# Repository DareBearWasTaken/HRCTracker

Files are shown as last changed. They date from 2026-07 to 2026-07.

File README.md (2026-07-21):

# Handheld Cadence Tracker

A responsive handheld walking and running cadence tracker built with an
ESP32-C5, an MPU9250-series inertial sensor, and a 128×64 SSD1306 OLED.

The tracker measures rhythmic handheld motion, filters out gravity and
orientation changes, validates step timing, and displays both the current and
average cadence in steps per minute (SPM). An LED provides immediate feedback
whenever a step is detected.

## Features

- 125 Hz accelerometer and gyroscope sampling
- Orientation-independent handheld motion detection
- Automatic stillness calibration at startup
- Adaptive accelerometer and gyroscope thresholds
- Hysteretic peak detection and false-motion rejection
- Rhythm locking for more reliable step validation
- Recovery from an occasional missed step impact
- Session step counter
- Average active cadence display
- Responsive current cadence display
- Immediate, non-blocking LED step indication
- OLED and sensor access coordinated to protect sample timing
- No button required

## Display

During tracking, the OLED shows:

- **AVG SPM:** Average cadence across accepted active step intervals
- **NOW:** Smoothed current cadence
- **STEPS:** Total confirmed and recovered steps
- **MOT:** Live motion-strength indicator
- **AVG CAD / AVG SEEK:** Whether a stable walking or running rhythm has been
  established

Pauses and rejected hand movements are not included in the average cadence.
The average remains available if rhythm lock is temporarily lost.

## Hardware

- ESP32-C5 development board
- MPU9250, MPU9255, or MPU6500 motion sensor
- 128×64 SSD1306 I²C OLED at address `0x3C` or `0x3D`
- Indicator LED
- 220–330 Ω LED resistor
- Jumper wires or a custom PCB

## Wiring

The firmware defaults to the original split-bus wiring below.

| Device | Signal | ESP32-C5 pin |
|---|---|---:|
| OLED | SDA | GPIO23 |
| OLED | SCL | GPIO24 |
| MPU | SDA | GPIO25 |
| MPU | SCL | GPIO26 |
| LED | Anode through 220–330 Ω resistor | GPIO2 |
| LED | Cathode | GND |

Connect the ESP32-C5, OLED, and MPU grounds together. Power each module using
the voltage supported by the specific breakout board being used.

The ESP32-C5 has one high-performance I²C controller that can be routed to the
arbitrary GPIO pins above. The firmware therefore locks the controller during
an OLED transfer, selects the OLED pins, transmits one frame, restores the MPU
pins, and releases the sensor task. The display refresh is limited to 2 FPS so
these interruptions remain short and infrequent.

## Firmware requirements

- Arduino IDE 2.x
- Espressif ESP32 Arduino core with ESP32-C5 support
- [Adafruit GFX Library](https://github.com/adafruit/Adafruit-GFX-Library)
- [Adafruit SSD1306](https://github.com/adafruit/Adafruit_SSD1306)

The MPU is configured directly through its registers. A separate MPU9250
Arduino library is not required.

## Installation

1. Install the Espressif ESP32 board package in Arduino IDE.
2. Install **Adafruit GFX Library** and **Adafruit SSD1306** using Library
   Manager.
3. Open [`cadence_tracker_screen_average.ino`](cadence_tracker_screen_average.ino).
4. Select **ESP32C5 Dev Module** as the board.
5. Select the correct serial port.
6. Compile and upload the sketch.

The firmware has been compile-tested with the following board identifier:

```text
esp32:esp32:esp32c5
```

## Using the tracker

1. Turn on or reset the tracker.
2. Confirm that the LED flashes three times during its startup test.
3. Hold the tracker completely still while the calibration screen reaches
   100%.
4. Hold the tracker naturally and begin walking or running.
5. The first valid motion flashes the LED immediately.
6. Two plausibly timed detections establish rhythm lock and begin the cadence
   display.

If the device moves repeatedly during calibration, the stable calibration
window restarts automatically.

## How cadence is calculated

The accelerometer magnitude is used so detection does not depend on the
orientation of the device. A slow baseline removes gravity and gradual hand
orientation changes. Filtered gyroscope motion then corroborates the
acceleration signal.

Candidate peaks must satisfy motion-strength, timing, and refractory-period
checks. After rhythm lock:

- Recent accepted intervals produce the responsive **NOW** cadence.
- All accepted active intervals produce the session **AVG SPM** cadence.
- A gap near two expected periods can recover one weak or missed impact.
- Pauses and rejected peaks do not lower the active-cadence average.

## Configuration and tuning

The default values are intended as a balanced starting point for handheld
walking and running. Test the tracker before changing them.

Useful constants near the top of the sketch include:

| Constant | Purpose |
|---|---|
| `SENSOR_PERIOD_MS` | Sensor sampling interval |
| `DISPLAY_PERIOD_MS` | OLED refresh interval |
| `MIN_STEP_INTERVAL_MS` | Maximum allowed cadence |
| `MAX_STEP_INTERVAL_MS` | Minimum cadence used while seeking rhythm |
| `PEAK_TRIGGER_SCORE` | Motion strength required to open a candidate peak |
| `PEAK_RELEASE_SCORE` | Hysteresis level used to finish a peak |

For missed real steps, reduce the lower acceleration-threshold clamp slightly.
For false steps caused by ordinary hand movement, increase
`PEAK_TRIGGER_SCORE` in small increments. Change only one value at a time and
test at multiple walking and running speeds.

## KiCad hardware files

KiCad design files for the custom cadence-tracker hardware will be added to
this repository. The planned hardware release includes:

- KiCad project file (`.kicad_pro`)
- Schematic (`.kicad_sch`)
- PCB layout (`.kicad_pcb`)
- Component and connector details
- Fabrication outputs and a bill of materials when available

A recommended repository location is:

```text
hardware/
└── kicad/
    ├── handheld_cadence_tracker.kicad_pro
    ├── handheld_cadence_tracker.kicad_sch
    └── handheld_cadence_tracker.kicad_pcb
```

Until those files are uploaded, the wiring table above is the reference for
building the prototype.

## Suggested repository structure

```text
.
├── cadence_tracker_screen_average.ino
├── README.md
├── hardware/
│   └── kicad/                 # KiCad files will be added here
└── docs/                      # Optional photos and build notes
```

## Troubleshooting

### OLED remains blank

- Confirm SDA is connected to GPIO23 and SCL to GPIO24.
- Confirm the OLED is an I²C SSD1306 display.
- Check whether its address is `0x3C` or `0x3D`; the firmware tries both.
- Verify common ground and the module's supply voltage.
- Open Serial Monitor at 115200 baud and check for `OLED not found`.

### Tracker stays on the calibration screen

Place it on a stable surface or hold it completely still. Sustained movement
intentionally restarts calibration.

### Cadence remains blank

The tracker needs two plausibly timed motion peaks before rhythm lock. Confirm
that the LED responds while walking naturally.

### MPU initialization fails

- Confirm SDA is connected to GPIO25 and SCL to GPIO26.
- Check power and ground.
- The firmware checks MPU addresses `0x68` and `0x69` automatically.

No license has been selected yet. Add a `LICENSE` file before distributing or
accepting contributions if you want to define reuse terms explicitly.

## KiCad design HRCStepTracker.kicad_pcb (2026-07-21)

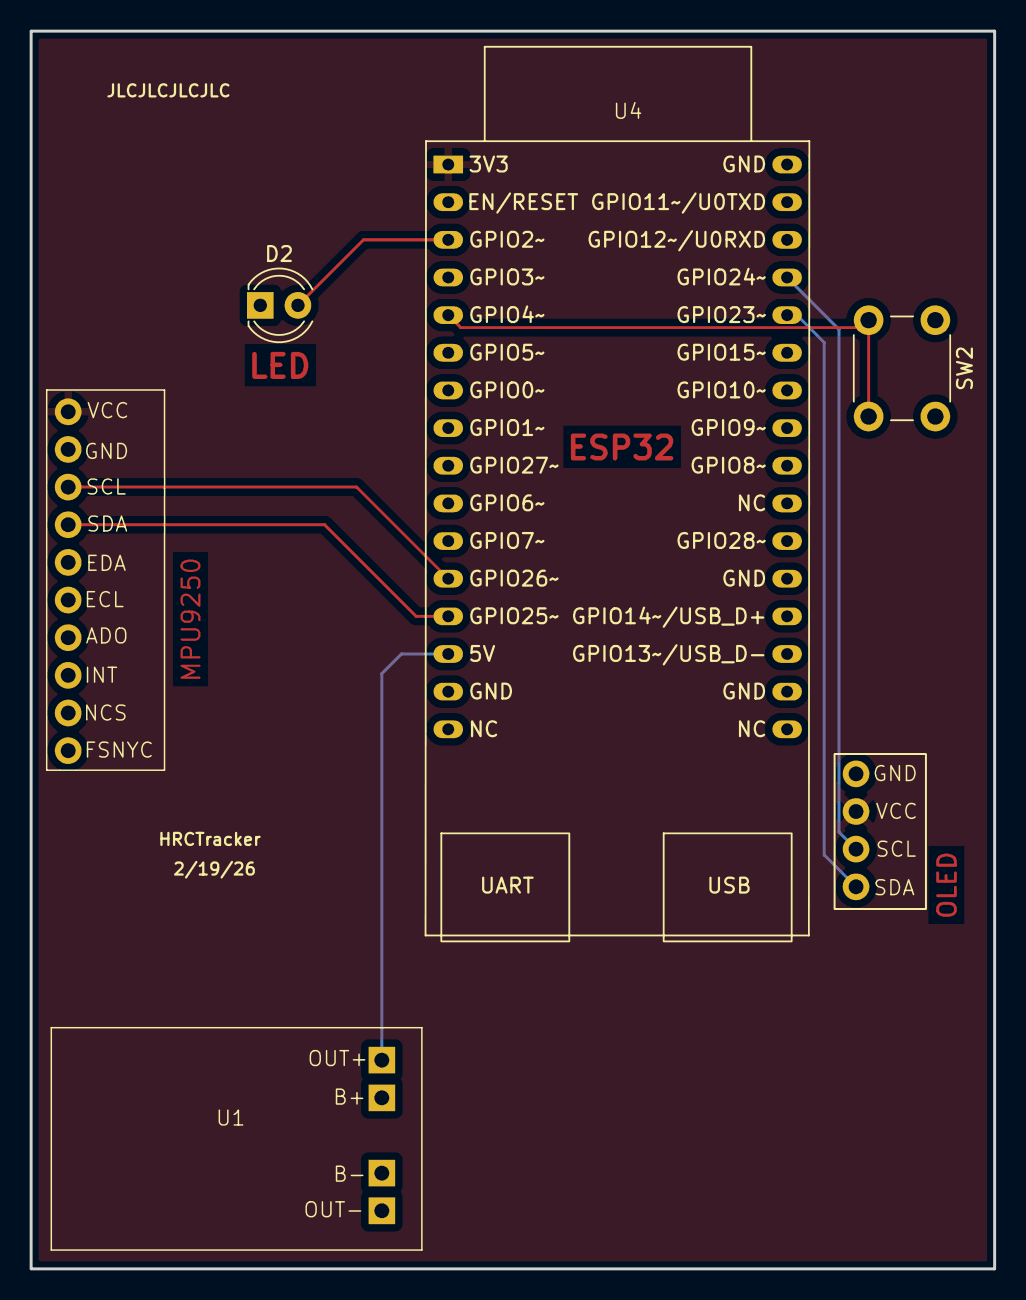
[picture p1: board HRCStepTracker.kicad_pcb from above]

Board: 4 copper layers, 65.0 x 83.5 mm, 6 parts (0 on the bottom side), 9 nets.

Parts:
D2: LED; LED_D4.0mm
SW2: SW_Push; SW_PUSH_6mm_H4.3mm
U1: TP4056
U4: ESP32-C5-DevKitC-1
U5: SSD1306
U6: MPU6500

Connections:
+3V3: U4.1 (3V3), U5.2 (VCC), U6.1 (VCC)
+5V: U1.1 (OUT+), U4.14 (5V)
GND: D2.1 (K), SW2.1, U1.4 (OUT-), U4.15 (GND), U4.18 (GND), U4.21 (GND), U4.32 (GND), U5.1 (GND), U6.2 (GND)
unnamed: D2.2 (A), U4.3 (GPIO2/MTMS)
unnamed: SW2.2, U4.5 (GPIO4/MTCK)
unnamed: U4.28 (GPIO23), U5.4 (SDA)
unnamed: U4.29 (GPIO24), U5.3 (SCL)
unnamed: U4.13 (GPIO25), U6.4 (SDA)
unnamed: U4.12 (GPIO26), U6.3 (SCL)

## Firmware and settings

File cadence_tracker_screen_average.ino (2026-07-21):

#include <Wire.h>
#include <Adafruit_GFX.h>
#include <Adafruit_SSD1306.h>
#include <math.h>
#include <string.h>

// ============================================================
// HANDHELD CADENCE TRACKER -- low-latency ESP32-C5 edition
// ============================================================
//
// Default wiring (matches the original tracker):
//   OLED SDA -> GPIO23      OLED SCL -> GPIO24
//   MPU SDA  -> GPIO25      MPU SCL  -> GPIO26
//   LED +    -> GPIO2 through a 220-330 ohm resistor
//   LED -    -> GND
//
// ESP32-C5 has only one high-performance I2C controller that can use
// these arbitrary pins. This version safely locks that controller,
// changes pins for the OLED frame, restores the MPU pins, and then
// releases the sensor task. The OLED updates at 2 Hz, keeping the
// unavoidable sampling interruption short and infrequent.
// ============================================================

#ifndef USE_ORIGINAL_WIRING
#define USE_ORIGINAL_WIRING 1
#endif

#ifndef ENABLE_STEP_DEBUG
#define ENABLE_STEP_DEBUG 0
#endif

// ------------------------------------------------------------
// Hardware
// ------------------------------------------------------------

constexpr int MPU_SDA_PIN = 25;
constexpr int MPU_SCL_PIN = 26;

#if USE_ORIGINAL_WIRING
constexpr int OLED_SDA_PIN = 23;
constexpr int OLED_SCL_PIN = 24;
constexpr int LED_PIN = 2;
#define OLED_WIRE Wire
#else
// Optional maximum-performance wiring using the C5's fixed LP-I2C pins.
constexpr int OLED_SDA_PIN = 2;
constexpr int OLED_SCL_PIN = 3;
constexpr int LED_PIN = 4;
#define OLED_WIRE Wire1
#endif

constexpr bool LED_ACTIVE_HIGH = true;
constexpr uint32_t I2C_CLOCK_HZ = 400000;
constexpr uint16_t I2C_TIMEOUT_MS = 8;

// ------------------------------------------------------------
// OLED
// ------------------------------------------------------------

constexpr int SCREEN_WIDTH = 128;
constexpr int SCREEN_HEIGHT = 64;
constexpr int OLED_RESET_PIN = -1;

// Keeping clkDuring and clkAfter at 400 kHz avoids an extra clock change
// during each safely time-sliced OLED update.
Adafruit_SSD1306 display(
  SCREEN_WIDTH,
  SCREEN_HEIGHT,
  &OLED_WIRE,
  OLED_RESET_PIN,
  I2C_CLOCK_HZ,
  I2C_CLOCK_HZ
);

bool displayAvailable = false;
uint8_t oledAddress = 0;

// ------------------------------------------------------------
// MPU9250 registers and scale factors
// ------------------------------------------------------------

constexpr uint8_t MPU_ADDRESS_LOW = 0x68;
constexpr uint8_t MPU_ADDRESS_HIGH = 0x69;

constexpr uint8_t REG_SMPLRT_DIV = 0x19;
constexpr uint8_t REG_CONFIG = 0x1A;
constexpr uint8_t REG_GYRO_CONFIG = 0x1B;
constexpr uint8_t REG_ACCEL_CONFIG = 0x1C;
constexpr uint8_t REG_ACCEL_CONFIG_2 = 0x1D;
constexpr uint8_t REG_INT_PIN_CFG = 0x37;
constexpr uint8_t REG_INT_ENABLE = 0x38;
constexpr uint8_t REG_INT_STATUS = 0x3A;
constexpr uint8_t REG_PWR_MGMT_1 = 0x6B;
constexpr uint8_t REG_PWR_MGMT_2 = 0x6C;
constexpr uint8_t REG_WHO_AM_I = 0x75;

constexpr float ACCEL_COUNTS_PER_G = 8192.0f;   // +/-4 g
constexpr float GYRO_COUNTS_PER_DPS = 65.5f;    // +/-500 dps

uint8_t mpuAddress = 0;

// ------------------------------------------------------------
// Application and UI state
// ------------------------------------------------------------

enum AppState : uint8_t {
  STATE_CALIBRATING,
  STATE_TRACKING,
  STATE_ERROR
};

struct UiSnapshot {
  AppState state;
  float calibrationProgress;
  bool calibrationMoving;
  bool rhythmLocked;
  float averageCadence;
  float currentCadence;
  float motionScore;
  uint32_t stepCount;
  uint32_t sensorFailures;
  uint32_t missedDeadlines;
  uint32_t sessionStartedAt;
  char errorMessage[24];
};

UiSnapshot uiSnapshot = {
  STATE_CALIBRATING,
  0.0f,
  false,
  false,
  0.0f,
  0.0f,
  0.0f,
  0,
  0,
  0,
  0,
  "NONE"
};

portMUX_TYPE uiMux = portMUX_INITIALIZER_UNLOCKED;

AppState appState = STATE_CALIBRATING;
char errorMessage[24] = "NONE";

// ------------------------------------------------------------
// Timing
// ------------------------------------------------------------

constexpr uint32_t SENSOR_PERIOD_MS = 8;      // MPU configured for 125 Hz
constexpr uint32_t DISPLAY_PERIOD_MS = 500;   // 2 FPS; protects sensor timing
constexpr uint32_t CALIBRATION_SAMPLE_COUNT = 375; // 3 stable seconds

uint32_t lastDisplayAt = 0;
uint32_t sessionStartedAt = 0;

#if USE_ORIGINAL_WIRING
enum PrimaryBusTarget : uint8_t {
  PRIMARY_BUS_NONE,
  PRIMARY_BUS_MPU,
  PRIMARY_BUS_OLED
};

PrimaryBusTarget primaryBusTarget = PRIMARY_BUS_NONE;
SemaphoreHandle_t i2cAccessMutex = nullptr;
#endif

// ------------------------------------------------------------
// LED -- immediate, non-blocking pulse
// ------------------------------------------------------------

constexpr uint32_t LED_PULSE_MS = 45;
volatile bool ledIsOn = false;
volatile uint32_t ledOffAt = 0;
portMUX_TYPE ledMux = portMUX_INITIALIZER_UNLOCKED;

// ------------------------------------------------------------
// Motion sample
// ------------------------------------------------------------

float accelX = 0.0f;
float accelY = 0.0f;
float accelZ = 1.0f;
float accelMagnitude = 1.0f;

float gyroX = 0.0f;
float gyroY = 0.0f;
float gyroZ = 0.0f;
float gyroMagnitude = 0.0f;

uint32_t sensorFailures = 0;
uint32_t consecutiveSensorFailures = 0;
uint32_t missedDeadlines = 0;

enum SampleResult : uint8_t {
  SAMPLE_READY,
  SAMPLE_NOT_READY,
  SAMPLE_BUS_ERROR
};

// ------------------------------------------------------------
// Calibration (Welford running statistics)
// ------------------------------------------------------------

uint32_t calibrationSamples = 0;
uint16_t unstableCalibrationSamples = 0;
bool calibrationMoving = false;

float accelCalibrationMean = 0.0f;
float accelCalibrationM2 = 0.0f;

float gyroMeanX = 0.0f;
float gyroMeanY = 0.0f;
float gyroMeanZ = 0.0f;

float gyroM2X = 0.0f;
float gyroM2Y = 0.0f;
float gyroM2Z = 0.0f;

float accelCalibrationNoise = 0.0f;
float gyroCalibrationNoise = 0.0f;

float gyroBiasX = 0.0f;
float gyroBiasY = 0.0f;
float gyroBiasZ = 0.0f;

// ------------------------------------------------------------
// Filters and adaptive thresholds
// ------------------------------------------------------------

// Coefficients assume an 8 ms sample interval. They correspond to a
// slow 0.35 Hz baseline and roughly 8-9 Hz motion low-pass filters.
constexpr float GRAVITY_ALPHA = 0.0173f;
constexpr float ACCEL_ENVELOPE_ALPHA = 0.3110f;
constexpr float GYRO_ENVELOPE_ALPHA = 0.2870f;
constexpr float NOISE_FLOOR_ALPHA = 0.0030f;

float gravityEstimate = 1.0f;
float accelEnvelope = 0.0f;
float gyroEnvelope = 0.0f;
float accelNoiseFloor = 0.005f;
float gyroNoiseFloor = 1.0f;

float baseAccelThreshold = 0.055f;
float baseGyroThreshold = 10.0f;
float activeAccelThreshold = 0.055f;
float activeGyroThreshold = 10.0f;
float combinedScore = 0.0f;

// A peak is opened at the high threshold and confirmed after the
// signal drops through the release threshold. This gives hysteresis
// without the double triggering common to simple threshold tests.
constexpr float PEAK_TRIGGER_SCORE = 1.00f;
constexpr float PEAK_RELEASE_SCORE = 0.58f;
constexpr uint32_t MAX_PEAK_WIDTH_MS = 190;

bool peakActive = false;
uint32_t peakStartedAt = 0;
uint32_t peakAt = 0;
float peakScore = 0.0f;
float peakAccel = 0.0f;
float peakGyro = 0.0f;

// ------------------------------------------------------------
// Cadence and rhythm
// ------------------------------------------------------------

constexpr uint32_t MIN_STEP_INTERVAL_MS = 260;   // 231 SPM ceiling
constexpr uint32_t MAX_STEP_INTERVAL_MS = 1500;  // 40 SPM floor
constexpr uint32_t MIN_LOCK_TIMEOUT_MS = 2400;

bool rhythmLocked = false;
uint32_t pendingCandidateAt = 0;
uint32_t lastCandidateAt = 0;

uint32_t stepCount = 0;
uint32_t lastStepAt = 0;

constexpr uint8_t INTERVAL_HISTORY_SIZE = 5;
uint32_t intervalHistory[INTERVAL_HISTORY_SIZE] = {0};
uint8_t intervalCount = 0;
uint8_t intervalWriteIndex = 0;

float smoothedIntervalMs = 0.0f;
float currentCadence = 0.0f;
float averageCadence = 0.0f;
uint64_t activeIntervalTotalMs = 0;
uint32_t activeIntervalCount = 0;

// ============================================================
// Forward declarations
// ============================================================

bool initializeBuses();
bool selectMPUBus();
bool selectOLEDBus();
bool transmitDisplayFrame();
bool initializeDisplay();
bool initializeMPU();
bool addressResponds(TwoWire &bus, uint8_t address);
bool writeMPURegister(uint8_t reg, uint8_t value);
bool readMPURegister(uint8_t reg, uint8_t &value);
SampleResult readMotionSample();

void sensorTask(void *parameter);
void beginCalibration();
void resetCalibrationStatistics(bool movementDetected);
void updateCalibration();
void finishCalibration();

void beginTracking();
void processHandheldMotion(uint32_t sampleAt);
void finishMotionPeak();
void processStepCandidate(uint32_t candidateAt);
void establishRhythmLock(uint32_t firstAt, uint32_t secondAt);
void registerConfirmedStep(
  uint32_t stepAt,
  uint8_t stepsToAdd,
  uint32_t normalizedInterval
);
void loseRhythmLock(uint32_t newPendingAt);
void checkRhythmTimeout(uint32_t now);

void clearIntervals();
void addInterval(uint32_t interval);
float robustIntervalMilliseconds();
void updateCadence();

void setLed(bool on);
void pulseLed();
void serviceLed();

void publishUiSnapshot();
UiSnapshot copyUiSnapshot();
void updateDisplay();
void drawCalibrationScreen(const UiSnapshot &snapshot);
void drawTrackingScreen(const UiSnapshot &snapshot);
void drawErrorScreen(const UiSnapshot &snapshot);
void drawTopLine(const char *leftText, const char *rightText);
void drawBar(int x, int y, int width, int height, float fraction);
void formatTime(uint32_t totalSeconds, char *buffer, size_t size);

void enterError(const char *message);

// ============================================================
// I2C and hardware initialization
// ============================================================

bool initializeBuses() {
#if USE_ORIGINAL_WIRING
  i2cAccessMutex = xSemaphoreCreateMutex();
  if (i2cAccessMutex == nullptr) {
    return false;
  }

  return selectMPUBus();
#else
  if (!Wire.begin(MPU_SDA_PIN, MPU_SCL_PIN, I2C_CLOCK_HZ)) {
    return false;
  }

  if (!Wire1.begin(OLED_SDA_PIN, OLED_SCL_PIN, I2C_CLOCK_HZ)) {
    return false;
  }

  Wire.setClock(I2C_CLOCK_HZ);
  Wire.setTimeOut(I2C_TIMEOUT_MS);
  Wire1.setClock(I2C_CLOCK_HZ);
  Wire1.setTimeOut(I2C_TIMEOUT_MS);
  return true;
#endif
}

bool selectMPUBus() {
#if USE_ORIGINAL_WIRING
  if (primaryBusTarget == PRIMARY_BUS_MPU) {
    return true;
  }

  if (primaryBusTarget != PRIMARY_BUS_NONE) {
    Wire.end();
    delayMicroseconds(80);
  }

  if (!Wire.begin(MPU_SDA_PIN, MPU_SCL_PIN, I2C_CLOCK_HZ)) {
    primaryBusTarget = PRIMARY_BUS_NONE;
    return false;
  }

  Wire.setClock(I2C_CLOCK_HZ);
  Wire.setTimeOut(I2C_TIMEOUT_MS);
  primaryBusTarget = PRIMARY_BUS_MPU;
#endif
  return true;
}

bool selectOLEDBus() {
#if USE_ORIGINAL_WIRING
  if (primaryBusTarget == PRIMARY_BUS_OLED) {
    return true;
  }

  if (primaryBusTarget != PRIMARY_BUS_NONE) {
    Wire.end();
    delayMicroseconds(80);
  }

  if (!Wire.begin(OLED_SDA_PIN, OLED_SCL_PIN, I2C_CLOCK_HZ)) {
    primaryBusTarget = PRIMARY_BUS_NONE;
    return false;
  }

  Wire.setClock(I2C_CLOCK_HZ);
  Wire.setTimeOut(I2C_TIMEOUT_MS);
  primaryBusTarget = PRIMARY_BUS_OLED;
#endif
  return true;
}

bool transmitDisplayFrame() {
#if USE_ORIGINAL_WIRING
  if (i2cAccessMutex == nullptr ||
      xSemaphoreTake(i2cAccessMutex, portMAX_DELAY) != pdTRUE) {
    return false;
  }

  bool selected = selectOLEDBus();
  if (selected) {
    display.display();
  }

  bool restored = selectMPUBus();
  xSemaphoreGive(i2cAccessMutex);
  return selected && restored;
#else
  display.display();
  return true;
#endif
}

bool addressResponds(TwoWire &bus, uint8_t address) {
  bus.beginTransmission(address);
  return bus.endTransmission() == 0;
}

bool initializeDisplay() {
  if (!selectOLEDBus()) {
    return false;
  }

  if (addressResponds(OLED_WIRE, 0x3C)) {
    oledAddress = 0x3C;
  } else if (addressResponds(OLED_WIRE, 0x3D)) {
    oledAddress = 0x3D;
  }

  bool initialized = false;

  // periphBegin=false preserves the bus and pins configured above.
  if (oledAddress != 0 &&
      display.begin(SSD1306_SWITCHCAPVCC, oledAddress, true, false)) {
    display.clearDisplay();
    display.setTextColor(SSD1306_WHITE);
    display.setTextWrap(false);
    display.display();
    initialized = true;
  }

  bool restored = selectMPUBus();
  return initialized && restored;
}

bool writeMPURegister(uint8_t reg, uint8_t value) {
  Wire.beginTransmission(mpuAddress);
  Wire.write(reg);
  Wire.write(value);
  return Wire.endTransmission() == 0;
}

bool readMPURegister(uint8_t reg, uint8_t &value) {
  Wire.beginTransmission(mpuAddress);
  Wire.write(reg);

  if (Wire.endTransmission(false) != 0) {
    return false;
  }

  if (Wire.requestFrom(mpuAddress, static_cast<size_t>(1), true) != 1) {
    return false;
  }

  value = static_cast<uint8_t>(Wire.read());
  return true;
}
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
void loop() {
  serviceLed();

  uint32_t now = millis();
  if (now - lastDisplayAt >= DISPLAY_PERIOD_MS) {
    lastDisplayAt = now;
    updateDisplay();
  }

  // Let the higher-priority sensor task wake precisely every 8 ms.
  delay(1);
}

void sensorTask(void *parameter) {
  (void)parameter;

  TickType_t lastWake = xTaskGetTickCount();
  const TickType_t periodTicks = pdMS_TO_TICKS(SENSOR_PERIOD_MS);

  while (true) {
    vTaskDelayUntil(&lastWake, periodTicks);

    TickType_t nowTicks = xTaskGetTickCount();
    if (nowTicks - lastWake > periodTicks) {
      missedDeadlines++;
      lastWake = nowTicks;
    }

    SampleResult result = SAMPLE_BUS_ERROR;

#if USE_ORIGINAL_WIRING
    if (xSemaphoreTake(i2cAccessMutex, portMAX_DELAY) == pdTRUE) {
      if (selectMPUBus()) {
        result = readMotionSample();
      }
      xSemaphoreGive(i2cAccessMutex);
    }
#else
    result = readMotionSample();
#endif

    if (result == SAMPLE_BUS_ERROR) {
      sensorFailures++;
      consecutiveSensorFailures++;

      if (consecutiveSensorFailures == 20) {
        enterError("MPU READ FAILED");
      }
    } else if (result == SAMPLE_READY) {
      consecutiveSensorFailures = 0;
      uint32_t sampleAt = millis();

      if (appState == STATE_CALIBRATING) {
        updateCalibration();
      } else if (appState == STATE_TRACKING) {
        processHandheldMotion(sampleAt);
        checkRhythmTimeout(sampleAt);
      }
    }

    publishUiSnapshot();
  }
}

// ============================================================
// Calibration
// ============================================================

void beginCalibration() {
  appState = STATE_CALIBRATING;
  resetCalibrationStatistics(false);
  Serial.println("Calibration started.");
}

void resetCalibrationStatistics(bool movementDetected) {
  calibrationSamples = 0;
  unstableCalibrationSamples = 0;
  calibrationMoving = movementDetected;

  accelCalibrationMean = 0.0f;
  accelCalibrationM2 = 0.0f;

  gyroMeanX = 0.0f;
  gyroMeanY = 0.0f;
  gyroMeanZ = 0.0f;

  gyroM2X = 0.0f;
  gyroM2Y = 0.0f;
  gyroM2Z = 0.0f;
}

void updateCalibration() {
  bool stationary =
    accelMagnitude > 0.78f &&
    accelMagnitude < 1.22f &&
    gyroMagnitude < 35.0f;

  if (stationary && calibrationSamples >= 24) {
    float gyroDeltaX = gyroX - gyroMeanX;
    float gyroDeltaY = gyroY - gyroMeanY;
    float gyroDeltaZ = gyroZ - gyroMeanZ;
    float gyroDeltaMagnitude = sqrtf(
      gyroDeltaX * gyroDeltaX +
      gyroDeltaY * gyroDeltaY +
      gyroDeltaZ * gyroDeltaZ
    );

    stationary =
      fabsf(accelMagnitude - accelCalibrationMean) < 0.065f &&
      gyroDeltaMagnitude < 10.0f;
  }

  if (!stationary) {
    calibrationMoving = true;
    unstableCalibrationSamples++;

    // Require a continuous still window. Short tremors merely pause the
    // progress; sustained motion restarts the three-second window.
    if (unstableCalibrationSamples >= 10) {
      resetCalibrationStatistics(true);
    }
    return;
  }

  unstableCalibrationSamples = 0;
  calibrationSamples++;

  float n = static_cast<float>(calibrationSamples);

  float accelDelta = accelMagnitude - accelCalibrationMean;
  accelCalibrationMean += accelDelta / n;
  accelCalibrationM2 +=
    accelDelta * (accelMagnitude - accelCalibrationMean);

  float gyroDeltaX = gyroX - gyroMeanX;
  gyroMeanX += gyroDeltaX / n;
  gyroM2X += gyroDeltaX * (gyroX - gyroMeanX);

  float gyroDeltaY = gyroY - gyroMeanY;
  gyroMeanY += gyroDeltaY / n;
  gyroM2Y += gyroDeltaY * (gyroY - gyroMeanY);

  float gyroDeltaZ = gyroZ - gyroMeanZ;
  gyroMeanZ += gyroDeltaZ / n;
  gyroM2Z += gyroDeltaZ * (gyroZ - gyroMeanZ);

  if (calibrationSamples >= 24) {
    calibrationMoving = false;
  }

  if (calibrationSamples >= CALIBRATION_SAMPLE_COUNT) {
    finishCalibration();
  }
}

void finishCalibration() {
  if (calibrationSamples < 2) {
    enterError("NO SENSOR SAMPLES");
    return;
  }

  float divisor = static_cast<float>(calibrationSamples - 1);
  accelCalibrationNoise = sqrtf(accelCalibrationM2 / divisor);

  float gyroVarianceX = gyroM2X / divisor;
  float gyroVarianceY = gyroM2Y / divisor;
  float gyroVarianceZ = gyroM2Z / divisor;
  gyroCalibrationNoise = sqrtf(
    gyroVarianceX + gyroVarianceY + gyroVarianceZ
  );

  gyroBiasX = gyroMeanX;
  gyroBiasY = gyroMeanY;
  gyroBiasZ = gyroMeanZ;
  gravityEstimate = accelCalibrationMean;

  baseAccelThreshold = constrain(
    0.035f + 5.0f * accelCalibrationNoise,
    0.050f,
    0.130f
  );

  baseGyroThreshold = constrain(
    6.0f + 4.0f * gyroCalibrationNoise,
    9.0f,
    28.0f
  );

  accelNoiseFloor = fmaxf(0.005f, accelCalibrationNoise);
  gyroNoiseFloor = fmaxf(1.0f, gyroCalibrationNoise);

  Serial.printf(
    "Calibration complete: gravity=%.3fg accelNoise=%.4fg "
    "gyroNoise=%.2fdps\n",
    gravityEstimate,
    accelCalibrationNoise,
    gyroCalibrationNoise
  );
  Serial.printf(
    "Starting thresholds: accel=%.3fg gyro=%.1fdps\n",
    baseAccelThreshold,
    baseGyroThreshold
  );

  beginTracking();
}

// ============================================================
// Motion filtering and peak detection
// ============================================================

void beginTracking() {
  rhythmLocked = false;
  pendingCandidateAt = 0;
  lastCandidateAt = 0;

  stepCount = 0;
  lastStepAt = 0;

  clearIntervals();
  currentCadence = 0.0f;
  averageCadence = 0.0f;
  smoothedIntervalMs = 0.0f;
  activeIntervalTotalMs = 0;
  activeIntervalCount = 0;

  accelEnvelope = 0.0f;
  gyroEnvelope = 0.0f;
  combinedScore = 0.0f;

  peakActive = false;
  peakStartedAt = 0;
  peakAt = 0;
  peakScore = 0.0f;
  peakAccel = 0.0f;
  peakGyro = 0.0f;

  gravityEstimate = accelCalibrationMean;
  sessionStartedAt = millis();
  appState = STATE_TRACKING;

  Serial.println("Automatic tracking started.");
}

void processHandheldMotion(uint32_t sampleAt) {
  float correctedGyroX = gyroX - gyroBiasX;
  float correctedGyroY = gyroY - gyroBiasY;
  float correctedGyroZ = gyroZ - gyroBiasZ;

  float correctedGyroMagnitude = sqrtf(
    correctedGyroX * correctedGyroX +
    correctedGyroY * correctedGyroY +
    correctedGyroZ * correctedGyroZ
  );

  // Magnitude makes the detector independent of how the unit is held.
  // The slow baseline removes gravity and gradual orientation changes.
  gravityEstimate +=
    GRAVITY_ALPHA * (accelMagnitude - gravityEstimate);

  float dynamicAcceleration = fabsf(accelMagnitude - gravityEstimate);

  accelEnvelope += ACCEL_ENVELOPE_ALPHA *
    (dynamicAcceleration - accelEnvelope);
  gyroEnvelope += GYRO_ENVELOPE_ALPHA *
    (correctedGyroMagnitude - gyroEnvelope);

  activeAccelThreshold = fmaxf(
    baseAccelThreshold,
    accelNoiseFloor * 3.6f + 0.024f
  );
  activeAccelThreshold = constrain(
    activeAccelThreshold,
    baseAccelThreshold,
    0.240f
  );

  activeGyroThreshold = fmaxf(
    baseGyroThreshold,
    gyroNoiseFloor * 3.2f + 5.0f
  );
  activeGyroThreshold = constrain(
    activeGyroThreshold,
    baseGyroThreshold,
    65.0f
  );

  float accelRatio =
    accelEnvelope / fmaxf(activeAccelThreshold, 0.001f);
  float gyroRatio =
    gyroEnvelope / fmaxf(activeGyroThreshold, 0.1f);

  combinedScore = 0.70f * accelRatio + 0.30f * gyroRatio;

  bool corroboratedMotion =
    (accelRatio >= 1.00f && gyroRatio >= 0.55f) ||
    (gyroRatio >= 1.15f && accelRatio >= 0.65f) ||
    (accelRatio >= 1.60f);

  if (!peakActive) {
    // Learn quiet handheld motion only below the release level. This keeps
    // real walking from raising its own threshold and disappearing.
    if (combinedScore < PEAK_RELEASE_SCORE) {
      accelNoiseFloor += NOISE_FLOOR_ALPHA *
        (accelEnvelope - accelNoiseFloor);
      gyroNoiseFloor += NOISE_FLOOR_ALPHA *
        (gyroEnvelope - gyroNoiseFloor);
    }

    bool outsideRefractory =
      lastCandidateAt == 0 ||
      sampleAt - lastCandidateAt >= MIN_STEP_INTERVAL_MS;

    if (outsideRefractory &&
        combinedScore >= PEAK_TRIGGER_SCORE &&
        corroboratedMotion) {
      peakActive = true;
      peakStartedAt = sampleAt;
      peakAt = sampleAt;
      peakScore = combinedScore;
      peakAccel = accelEnvelope;
      peakGyro = gyroEnvelope;
    }
    return;
  }

  if (combinedScore > peakScore) {
    peakAt = sampleAt;
    peakScore = combinedScore;
    peakAccel = accelEnvelope;
    peakGyro = gyroEnvelope;
  }

  if (combinedScore <= PEAK_RELEASE_SCORE ||
      sampleAt - peakStartedAt >= MAX_PEAK_WIDTH_MS) {
    finishMotionPeak();
  }
}

void finishMotionPeak() {
  bool validShape =
    peakScore >= PEAK_TRIGGER_SCORE &&
    peakAccel < 2.5f &&
    peakGyro < 420.0f;

  if (validShape) {
    lastCandidateAt = peakAt;
    processStepCandidate(peakAt);
  }

  peakActive = false;
}
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
